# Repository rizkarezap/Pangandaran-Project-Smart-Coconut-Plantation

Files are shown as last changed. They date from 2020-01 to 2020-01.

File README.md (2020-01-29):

# Pangandaran Project: Smart Coconut Plantation
# Introduction

We see that some of our coconut farmers are having problems with their growing media. They cannot monitor the level of soil fertility in an exact manner so that they cannot provide proper care to the soil. From these problems we tried to make the device that we designed ergonomically. Farmers can use this tool easily and quick results with accuracy can be accounted for.

# The Device

We made this device using a microcontroller from the Arduino family, the Arduino Nano. We use analog pins to get data like
fertility,
pH
Light intensity,
soil moisture
simultaneously. The data is processed and displayed on a 64x64 LCD screen. Regarding the power source, we use a Lipo 3.7 V 800 mAh battery and add a charger module to recharge. We also added a Bluetooth communication module to send data from devices to smart devices, such as Android phones.

# The Tools

To make it easy to use, we recommend that you install the Arduino IDE. You can easily upload code using the device to the microcontroller that you are using.

# The Schematic

We make board designs that we have integrated with other devices. You can use Eagle CAD or KiCAD software to see the schematics we made.

# We Are Open To Discuss

We really hope to continue this product until we can distribute this device to a wider market. Therefore we expect your support. You can contact me through my email. All your support is very helpful for us.

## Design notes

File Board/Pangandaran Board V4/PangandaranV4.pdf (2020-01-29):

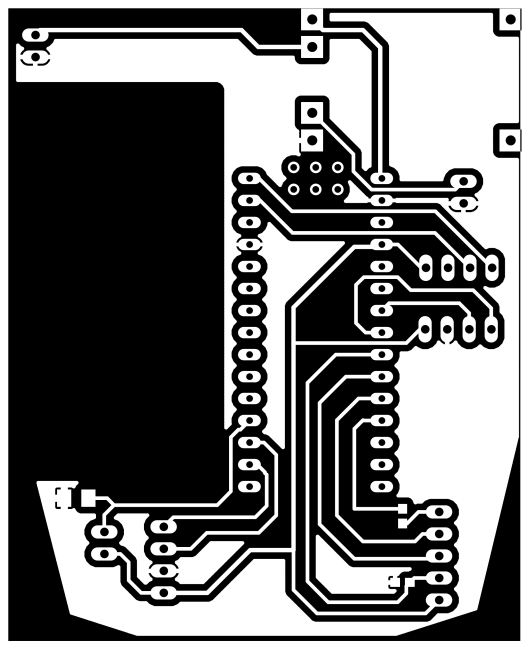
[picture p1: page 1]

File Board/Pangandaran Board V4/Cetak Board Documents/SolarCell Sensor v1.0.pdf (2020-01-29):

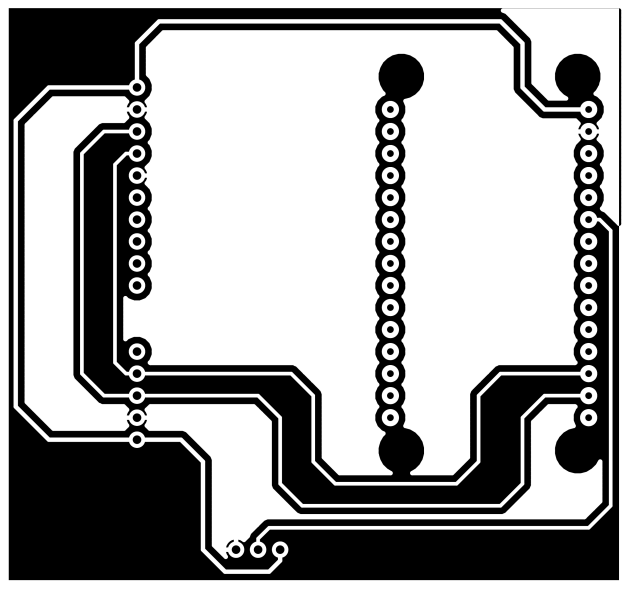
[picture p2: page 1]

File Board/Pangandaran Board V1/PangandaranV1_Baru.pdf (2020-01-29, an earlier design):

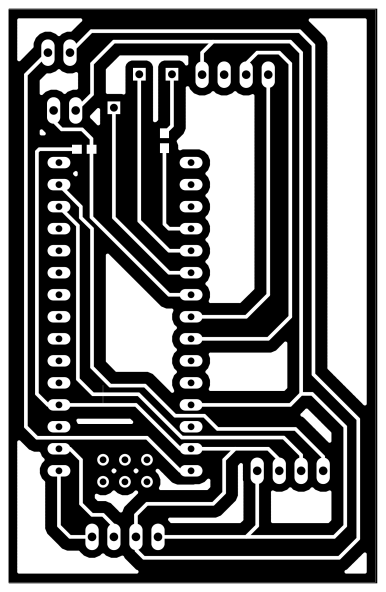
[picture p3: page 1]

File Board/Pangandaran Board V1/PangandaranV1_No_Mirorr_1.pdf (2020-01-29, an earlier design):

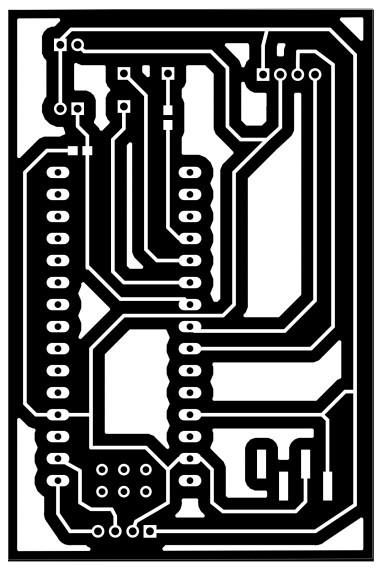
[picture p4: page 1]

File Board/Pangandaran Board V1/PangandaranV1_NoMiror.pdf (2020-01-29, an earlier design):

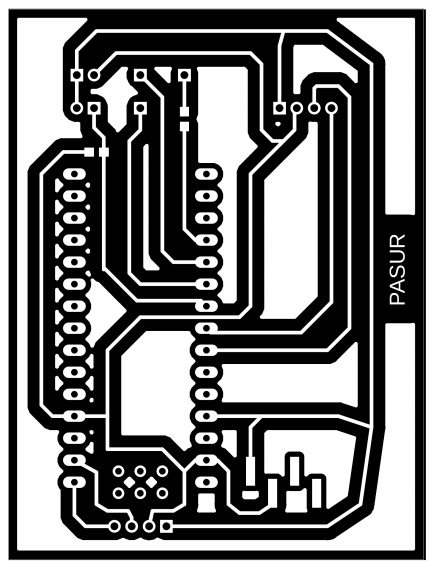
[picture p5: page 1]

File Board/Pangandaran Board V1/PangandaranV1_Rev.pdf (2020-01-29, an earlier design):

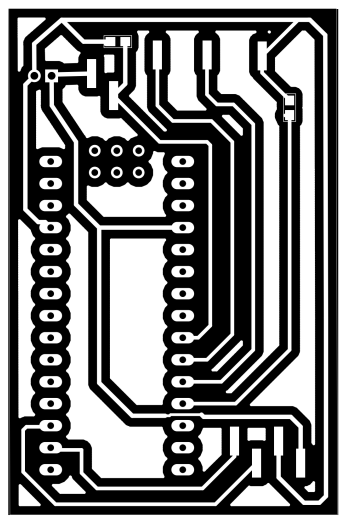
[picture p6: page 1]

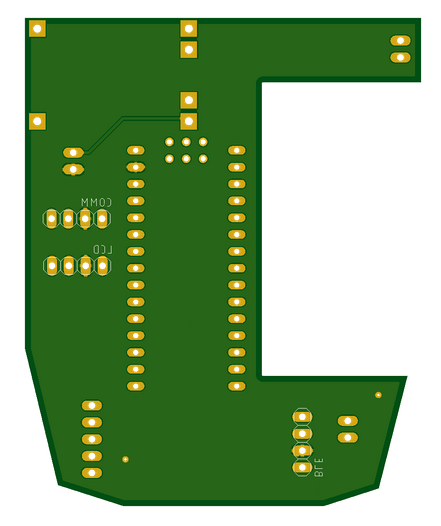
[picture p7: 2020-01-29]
Board/Bottom.png

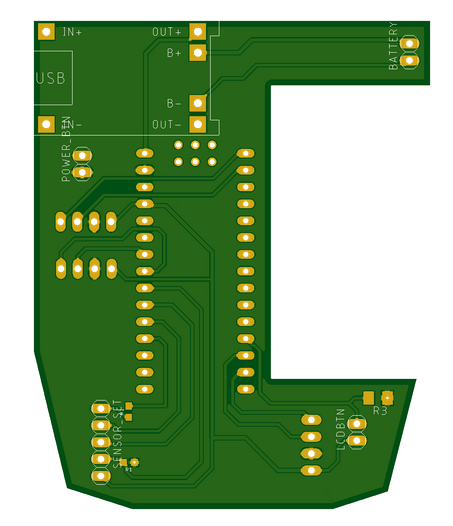
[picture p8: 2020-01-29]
Board/Top.png

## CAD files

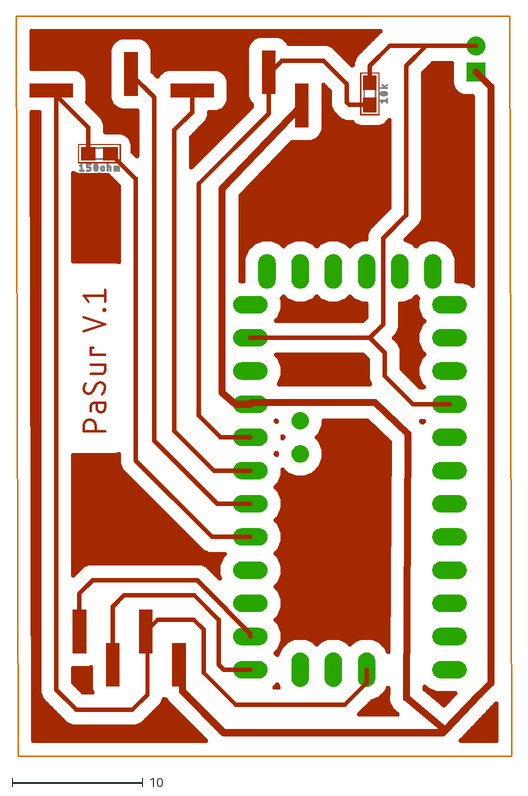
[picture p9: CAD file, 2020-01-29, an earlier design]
Board/Pangandaran Board V1/PangandaranV1.dxf
37.9 x 56.6

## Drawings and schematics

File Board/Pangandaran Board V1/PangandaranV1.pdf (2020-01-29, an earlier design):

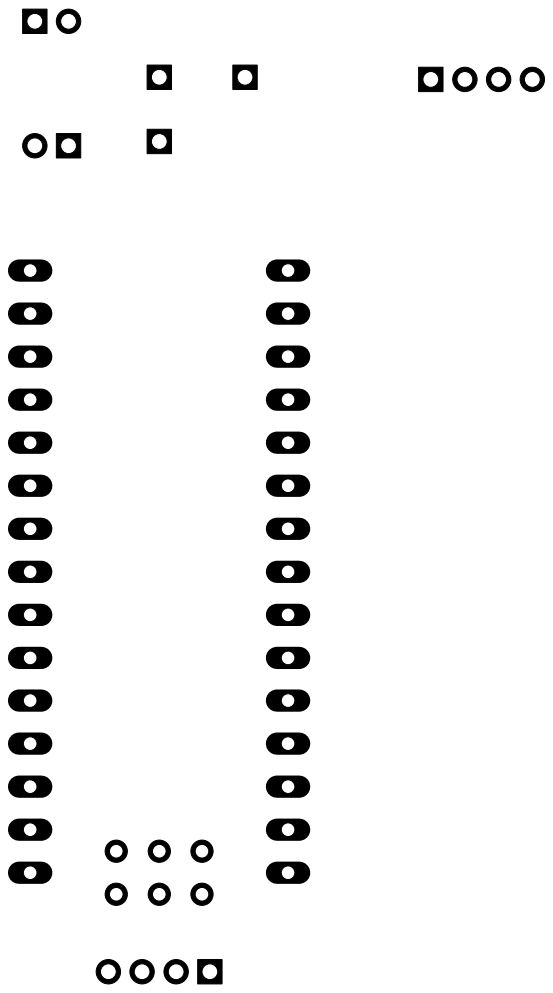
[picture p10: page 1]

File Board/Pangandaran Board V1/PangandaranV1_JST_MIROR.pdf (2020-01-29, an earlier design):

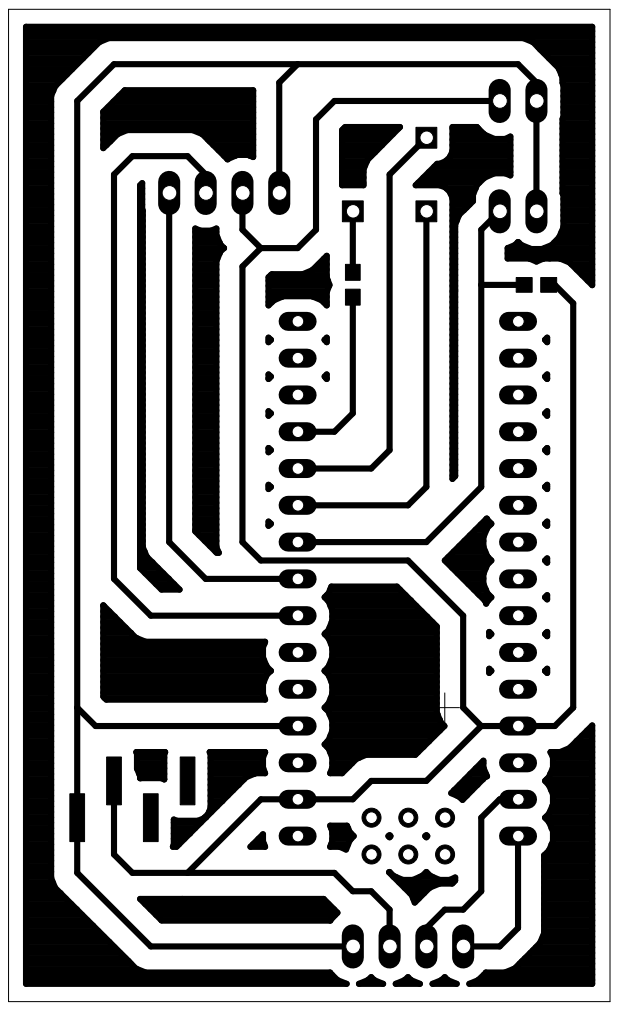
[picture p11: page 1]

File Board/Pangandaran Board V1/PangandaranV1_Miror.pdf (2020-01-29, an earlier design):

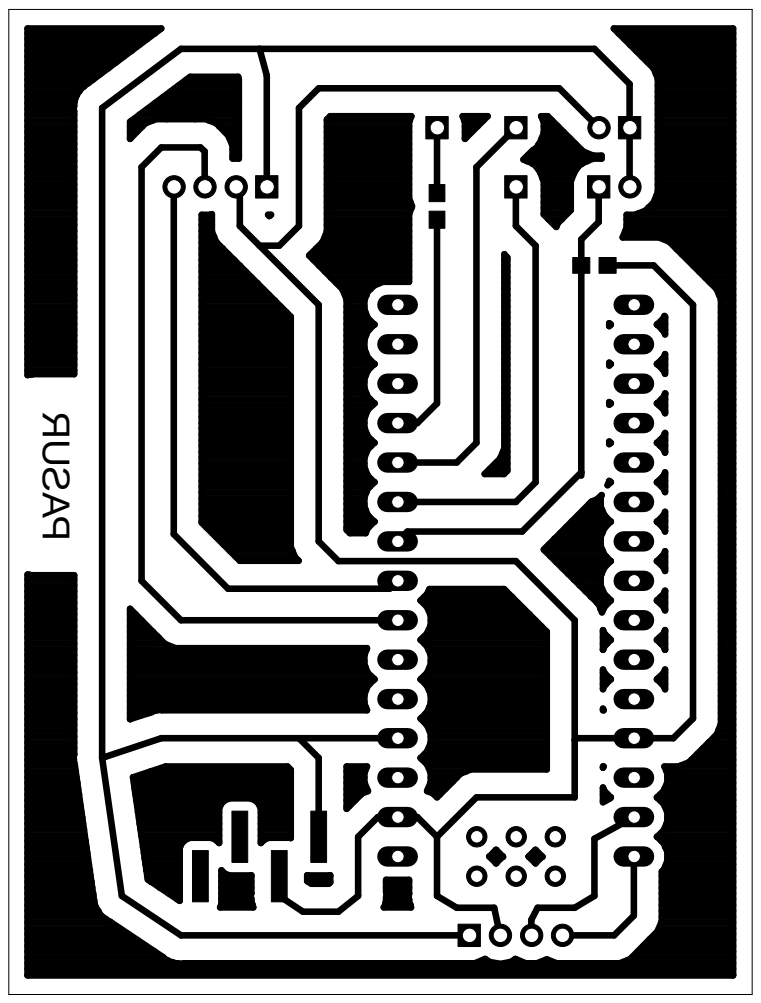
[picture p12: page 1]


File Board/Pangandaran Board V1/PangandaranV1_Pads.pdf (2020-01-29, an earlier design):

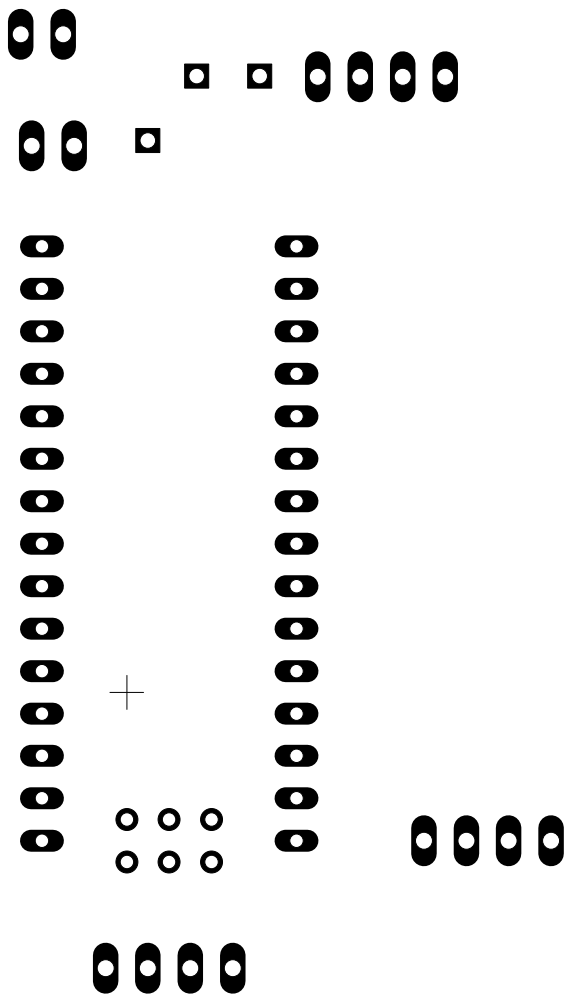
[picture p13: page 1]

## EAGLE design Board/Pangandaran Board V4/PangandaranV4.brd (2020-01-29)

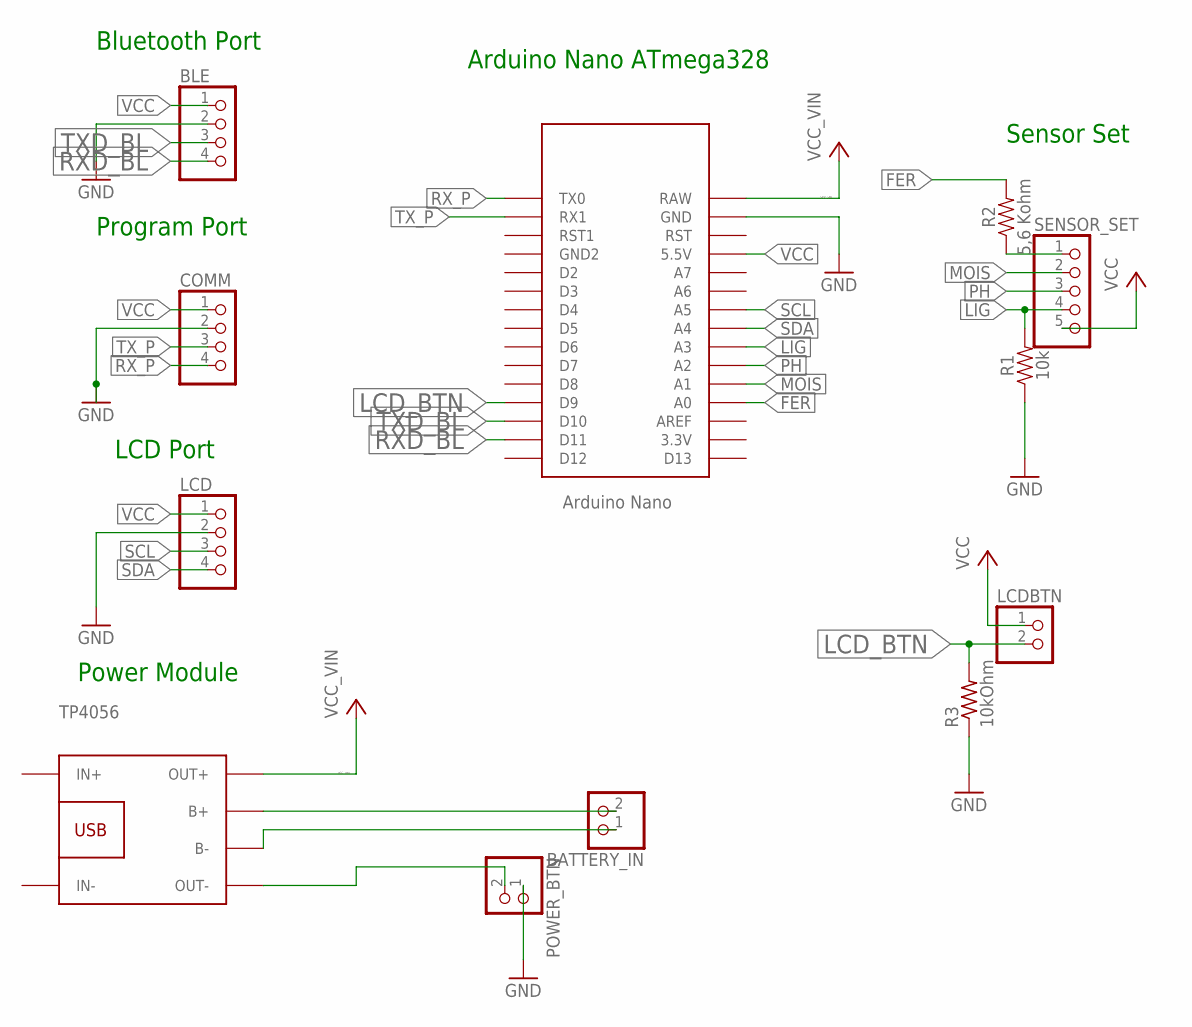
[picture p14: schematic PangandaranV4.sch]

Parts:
BATTERY_IN: PINHD-1X2; 1X02
BLE: PINHD-1X4; 1X04
COMM: PINHD-1X4; 1X04
LCD: PINHD-1X4; 1X04
LCDBTN: PINHD-1X2; 1X02
POWER_BTN: PINHD-1X2; 1X02
R1: 10k; 0603
R2: 5,6 Kohm; 0603
R3: 10kOhm; M1206
SENSOR_SET: PINHD-1X5; 1X05
TP4056: BATTERY-CHARGER-LI-PROT
U$2: NANO

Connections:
FER: R2.2, U$2.A0
GND: BLE.2, COMM.2, LCD.2, POWER_BTN.1, R1.1, R3.1, U$2.GND
LCD_BTN: LCDBTN.2, R3.2, U$2.D9
LIG: R1.2, SENSOR_SET.4, U$2.A3
MOIS: SENSOR_SET.2, U$2.A1
unnamed: R2.1, SENSOR_SET.1
unnamed: BATTERY_IN.2, TP4056.B+
unnamed: BATTERY_IN.1, TP4056.B-
unnamed: POWER_BTN.2, TP4056.OUT-
PH: SENSOR_SET.3, U$2.A2
RXD_BL: BLE.4, U$2.D11
RX_P: COMM.4, U$2.TX0
SCL: LCD.3, U$2.A5
SDA: LCD.4, U$2.A4
TXD_BL: BLE.3, U$2.D10
TX_P: COMM.3, U$2.RX1
VCC: BLE.1, COMM.1, LCD.1, LCDBTN.1, SENSOR_SET.5, U$2.5V (5.5V)
VCC_VIN: TP4056.OUT+, U$2.RAW

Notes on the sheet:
Power Module
Program Port
Arduino Nano ATmega328
LCD Port
Bluetooth Port
Sensor Set

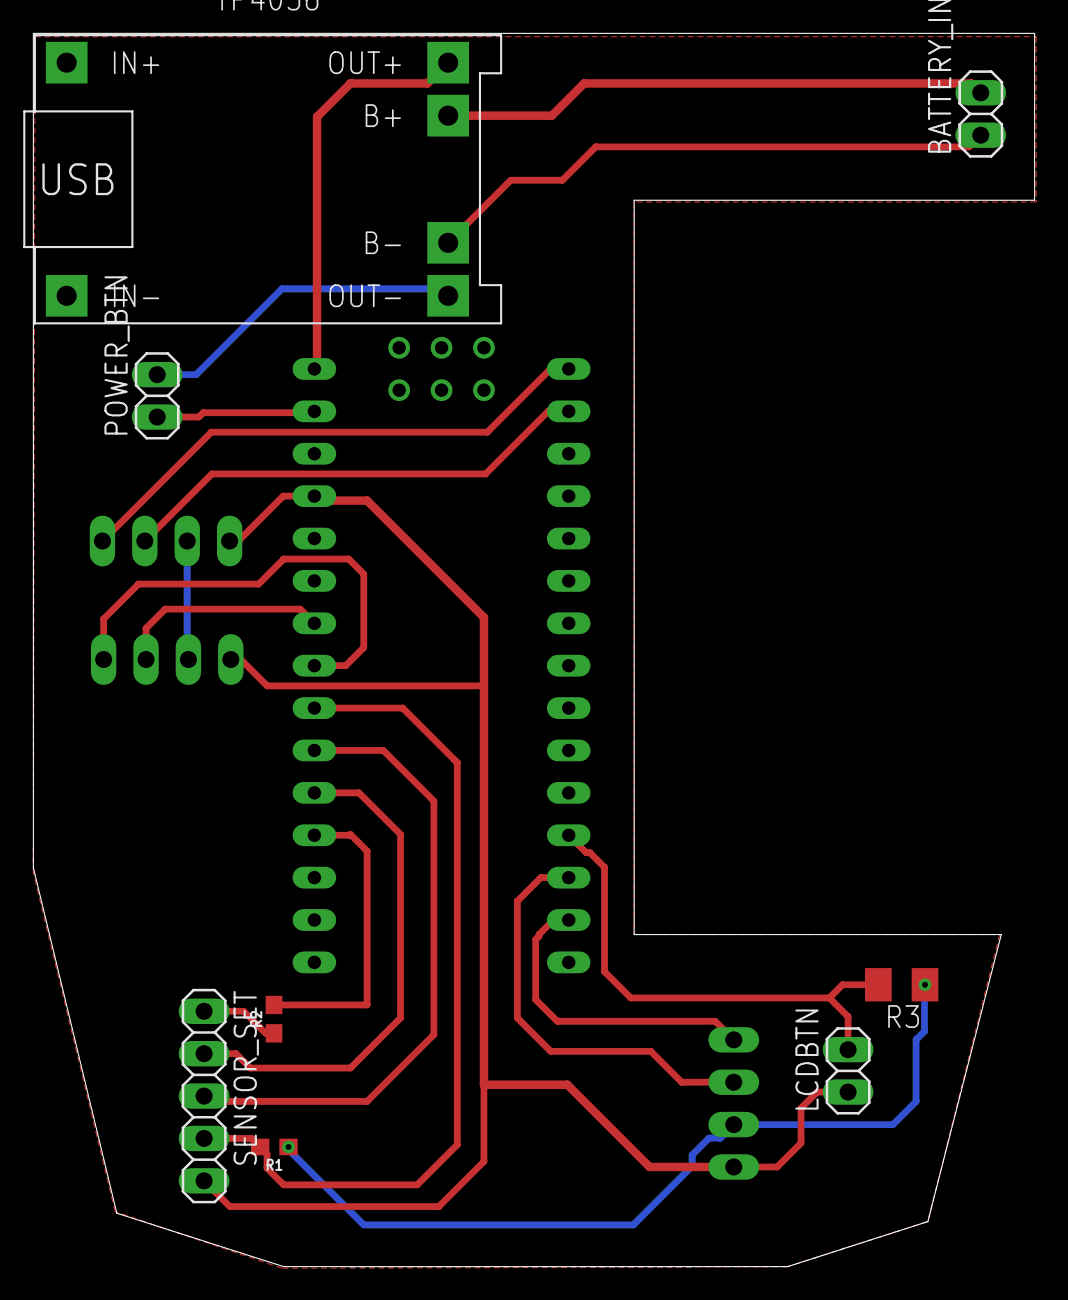
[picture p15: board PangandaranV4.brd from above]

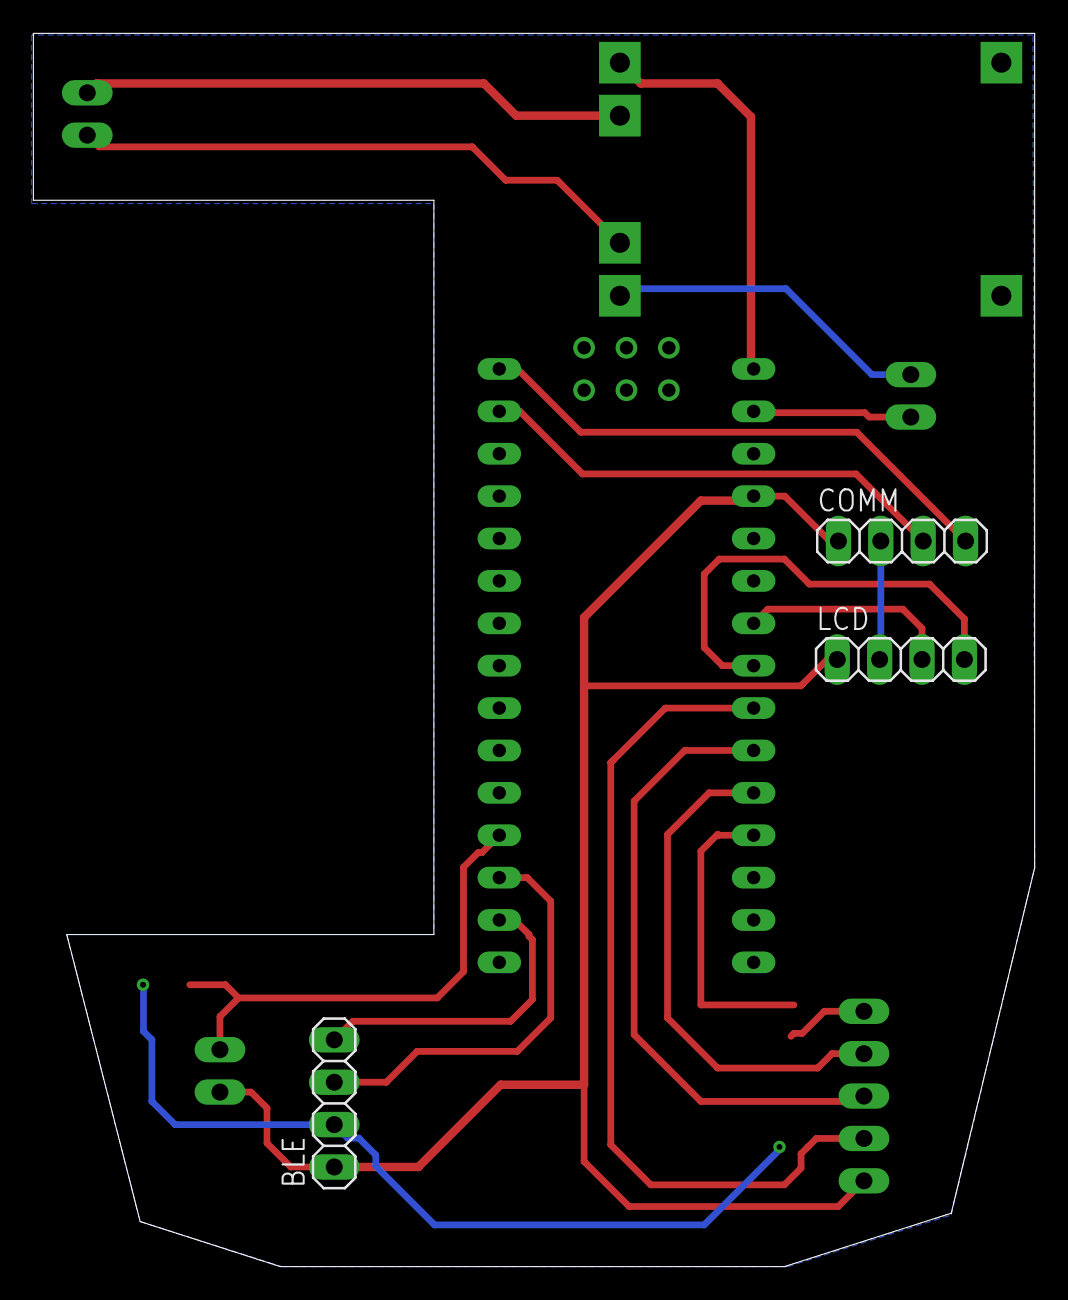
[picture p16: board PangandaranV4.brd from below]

Board: 2 copper layers, 60.0 x 73.9 mm, 12 parts (4 on the bottom side), 18 nets.

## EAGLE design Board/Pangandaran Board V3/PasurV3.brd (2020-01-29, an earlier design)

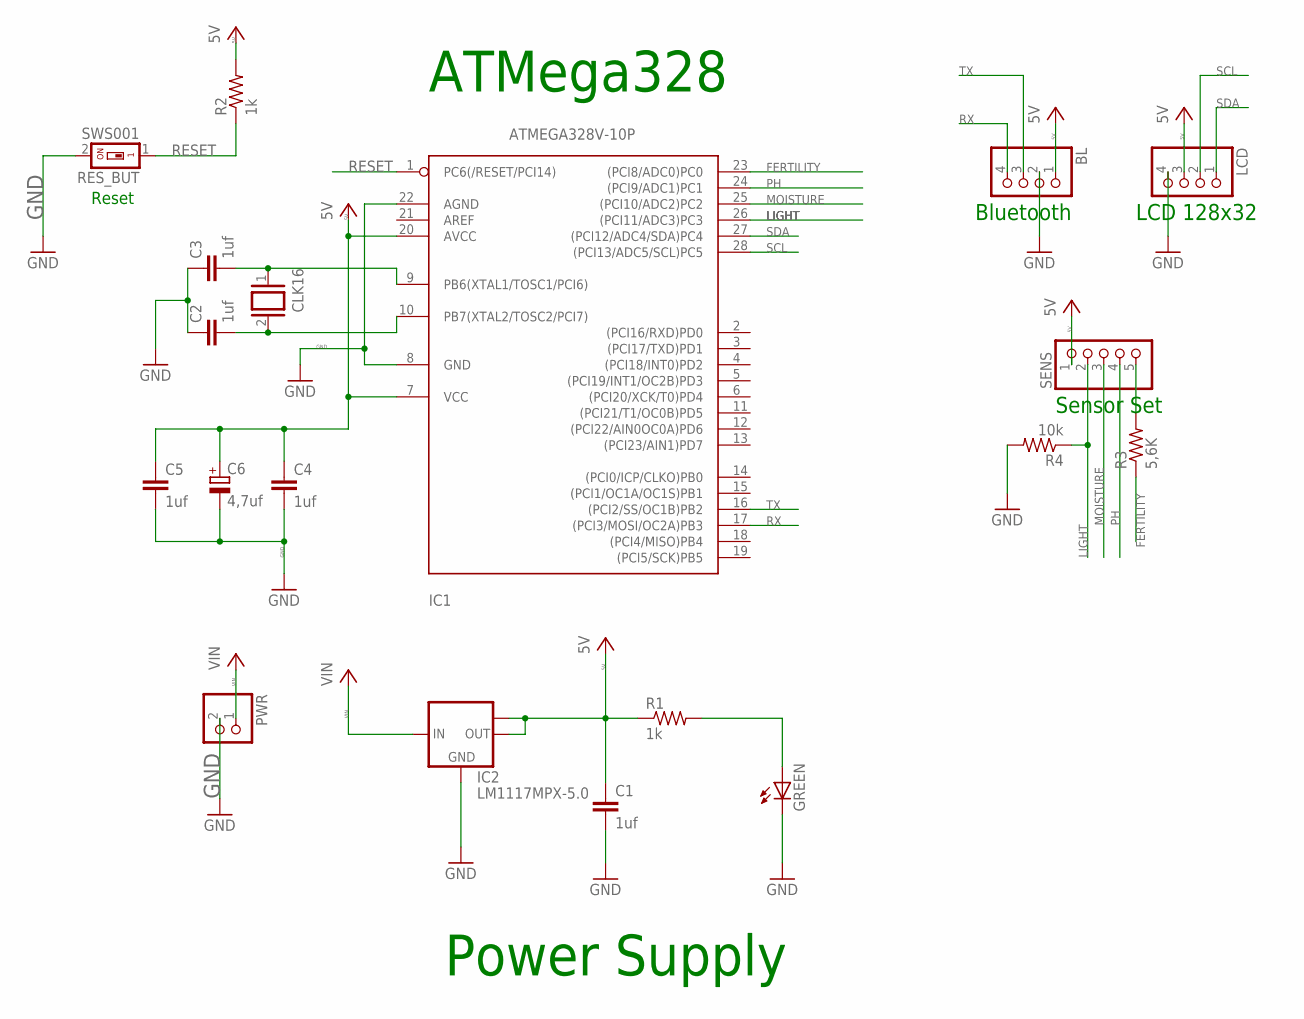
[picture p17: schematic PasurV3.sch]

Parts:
BL: PINHD-1X4; 1X04
C1, C2, C3, C4, C5: 1uf; C1206
C6: 4,7uf; A/3216-18W
CLK16: XTAL/S; QS
GREEN: LED_E; LED_1206
IC1: ATMEGA328V-10P; DIL28-3
IC2: LM1117MPX-5.0; SOT223
LCD: PINHD-1X4; 1X04
PWR: PINHD-1X2; 1X02
R1, R2: 1k; M1206
R3: 5,6K; M1206
R4: 10k; M1206
RES_BUT: SWS001; SMS-001
SENS: PINHD-1X5; 1X05

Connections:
5V: BL.1, C1.1, C4.1, C5.1, C6.+, IC1.7 (VCC), IC1.20 (AVCC), IC2.2 (OUT), IC2.TAB (OUT1), LCD.3, R1.1, R2.2, SENS.1
FERTILITY: IC1.23 ((PCI8/ADC0)PC0), R3.1
GND: BL.2, C1.2, C2.1, C3.1, C4.2, C5.2, C6.-, GREEN.C, IC1.8 (GND), IC1.22 (AGND), IC2.1 (GND), LCD.4, PWR.2, R4.2, RES_BUT.2
LIGHT: IC1.26 ((PCI11/ADC3)PC3), R4.1, SENS.2
MOISTURE: IC1.25 ((PCI10/ADC2)PC2), SENS.3
unnamed: C3.2, CLK16.1, IC1.9 (PB6(XTAL1/TOSC1/PCI6))
unnamed: C2.2, CLK16.2, IC1.10 (PB7(XTAL2/TOSC2/PCI7))
unnamed: GREEN.A, R1.2
unnamed: R3.2, SENS.5
PH: IC1.24 ((PCI9/ADC1)PC1), SENS.4
RESET: IC1.1 (PC6(/RESET/PCI14)), R2.1, RES_BUT.1
RX: BL.4, IC1.17 ((PCI3/MOSI/OC2A)PB3)
SCL: IC1.28 ((PCI13/ADC5/SCL)PC5), LCD.2
SDA: IC1.27 ((PCI12/ADC4/SDA)PC4), LCD.1
TX: BL.3, IC1.16 ((PCI2/SS/OC1B)PB2)
VIN: IC2.3 (IN), PWR.1

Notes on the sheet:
Power Supply
Reset
ATMega328
Bluetooth
LCD 128x32
Sensor Set

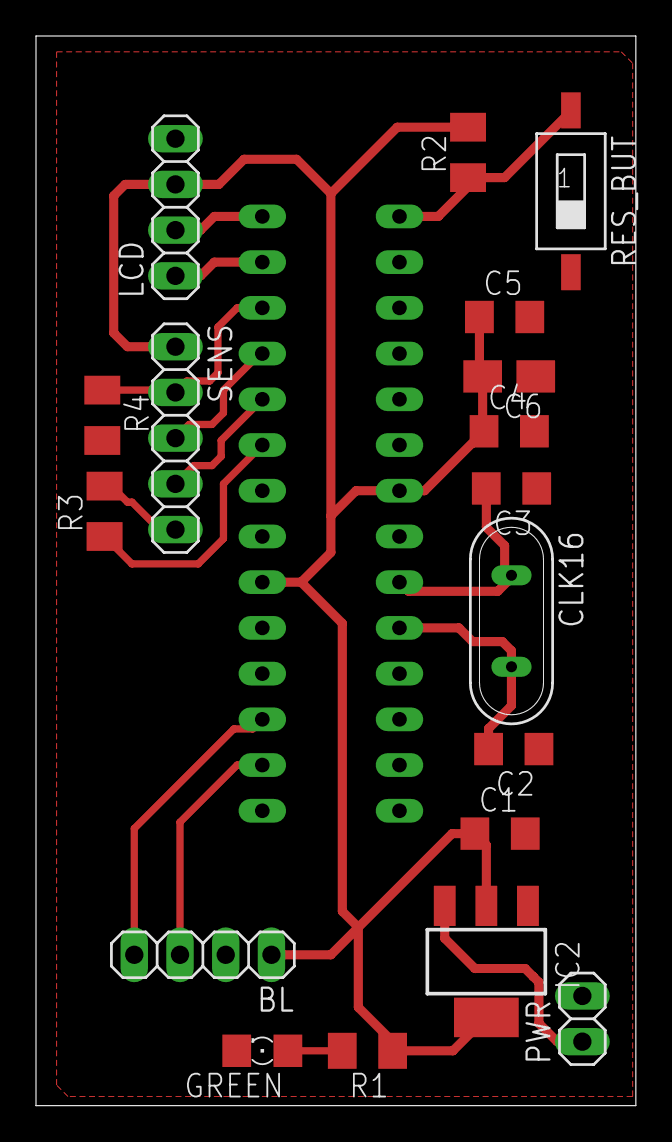
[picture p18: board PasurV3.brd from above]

Board: 2 copper layers, 33.3 x 59.4 mm, 19 parts (1 on the bottom side), 16 nets.

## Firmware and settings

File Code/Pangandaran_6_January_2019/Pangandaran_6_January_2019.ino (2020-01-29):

/*
   Dokumentasi pengerjaan code untuk proyek Pangandaran.

   Versi 1.01

   Pengerjaan board menggunakan arduino Nano

   Sensor yang digunakan adalah :
      1. pH
      2. Moistuer
      3. Fertility
      4. Cahaya

  Definisi Port untuk sensor
      1. pH ada di A2
      2. Moisture A1
      3. Fertility Perpauan A1 dan A0
      4. Cahaya A3


  Penambahan LCD pada tanggal 16 Juli 2018

   LCD yang digunakan adalah LCD 128*64 I2C 0X3C

  Penambahan Prosedur bahwa data yang dikirim adalah satu string dengan format pH, Moisture, Fertility, Cahaya dengan format "pH123#Mo123#Fe123#Li123"

    26 Juli 2018

  Perbahuran kode untuk pengambilan data pH. Pembaruan pengambilan data dilakukan karena pengambilan data pH tidak begitu akurat dan memiliki jangka nilai yang jauh.

   21 Desember

   Perbaruan kode yang ditujukan untuk dapat dengan mudah mengganti nilai kalibrasi pada perangkat. Sistem yang digunakan adalah dengan menyimpan data kalibrasi pada EEPEROM dengan deskripsi alamat sebagai berikut
      Address 0 : pH
      Address 1 : Moisture
      Address 2 & 3 : Fertility
      Address 4 : Light
*/


#include <SPI.h>
#include <Wire.h>
#include <SoftwareSerial.h>
#include <Adafruit_GFX.h>       // Lbrary Untuk Grapics LCD
#include <Adafruit_SSD1306.h>   // Library For LCD
#include <EEPROM.h>
/*
   Define Port Untuk sensor
*/
#define pH A2
#define Moisture A1
#define Fertility A0
#define Cahaya A3
#define LCD 9

int DatapH,DataMoisture,DataFertility,DataCahaya;
int PurepH,PureMos,PureFer,PureLi;
float KalpH = 99.198 ,KalMos = 102.337 ,KalFer = 321.13 ,KalLi = 102.3; // Default nilai pada kalibrasi
String readFromBLE = "",readKal = "";
int looppH = 0,signpH,loopFer = 0,signFer,loopMos = 0,signMos,loopLi = 0,signLi;

/*
   Define untuk LCD
*/
#define OLED_RESET 4
Adafruit_SSD1306 display(OLED_RESET);
#define NUMFLAKES 10
#define XPOS 0
#define YPOS 1
#define DELTAY 2
#define LOGO16_GLCD_HEIGHT 16
#define LOGO16_GLCD_WIDTH  16

static const unsigned char PROGMEM Logo_Light[] = // Logo Australia Global Alumni
{ B10000000, B00000001,
  B10000001, B10000001,
  B11000001, B10000011,
  B01100001, B10000110,
  B00000000, B00000000,
  B00000011, B11100000,
  B00000111, B11110000,
  B11011111, B11111011,
  B11011111, B11111011,
  B00001111, B11110000,
  B00000111, B11100000,
  B00000000, B00000000,
  B01100001, B10000110,
  B11000001, B10000011,
  B10000001, B10000001,
  B10000001, B10000001
};
static const unsigned char PROGMEM Logo_Moisture[] = // Logo Australia Global Alumni
{ B00000100, B00000000,
  B00000011, B00000000,
  B00000011, B1000000,
  B00000001, B11100000,
  B00000001, B11110000,
  B00000001, B11111000,
  B00000111, B11111100,
  B00011111, B11111110,
  B00111111, B11111111,
  B01111111, B11111111,
  B01111111, B11111111,
  B01111111, B11111111,
  B00111111, B11111110,
  B00011111, B11111110,
  B00001111, B11111000,
  B00000001, B11000000
};

static const unsigned char PROGMEM Logo_pH[] = // Logo Australia Global Alumni
{ B00000000, B00000000,
  B00000011, B00001100,
  B00000011, B00001100,
  B00000011, B00001100,
  B00000011, B11111100,
  B00000011, B00001100,
  B00000011, B00001100,
  B00000011, B11001100,
  B00111111, B11001100,
  B01100011, B1100000,
  B01100011, B11000000,
  B01100000, B11000000,
  B01111111, B11000000,
  B01100000, B00000000,
  B01100000, B00000000,
  B01100000, B00000000
};

static const unsigned char PROGMEM Logo_Fertility[] = // Logo Australia Global Alumni
{ B00000000, B00011111,
  B00000000, B00111111,
  B11000000, B01111111,
  B11111100, B01111110,
  B01111110, B00011100,
  B01111110, B01110000,
  B01111111, B11100000,
  B00000011, B00000000,
  B00001111, B00000000,
  B00011100, B00000000,
  B01111000, B00000000,
  B01110000, B00000000,
  B01110000, B00000000,
  B11110000, B00000000,
  B11100000, B00000000,
  B11100000, B00000000
};


SoftwareSerial BlueT(10, 11); // RX | TX

void setup()   {
  BlueT.begin(9600);
  display.begin(SSD1306_SWITCHCAPVCC, 0x3C);  // initialize with the I2C addr 0x3C (for the 128x64)
  display.clearDisplay();
  pinMode(LCD, INPUT);
  delay(1000);
  testscrolltext();
  ReadEEPROM();
  //Serial.begin(9600);
}

void loop() {

  if (digitalRead(LCD))
  {
    /*
       Get Data Moisture
    */
    DataMoisture = analogRead(Moisture);
    while (loopMos < 10 ) {
      if (loopMos == 0) {
        signMos = DataMoisture;
        loopMos++;
      }
      else if (abs(DataMoisture - signMos) < 150) {
        loopMos ++;
      }
      else {
        loopMos = 0;
      }
      delay(50);
      DataMoisture = analogRead(Moisture);
    }
    loopMos = 0;
    PureMos = DataMoisture / KalMos ;
    display.clearDisplay();
    /*
        Get Data Fertility
    */
    DataFertility = analogRead(Fertility);
    while (loopFer < 10 ) {
      if (loopFer == 0) {
        signFer = DataFertility;
        loopFer++;
      }
      else if (abs(DataFertility - signFer) < 340) {
        loopFer ++;
      }
      else {
        loopFer = 0;
      }
      delay(50);
      DataFertility = analogRead(Fertility);
    }
    loopFer = 0;
    DataFertility = DataFertility + DataMoisture;
    PureFer = (DataFertility / KalFer);
    /*
       Get Data Light
    */
    int DataCahaya = analogRead(Cahaya);
    PureLi = DataCahaya / KalLi;
    /*
       Get Data pH
    */
    DatapH = analogRead(pH);
    while (looppH < 10 ) {
      if (looppH == 0) {
        signpH = DatapH;
        looppH++;
      }
      else if (abs(DatapH - signpH) < 120) {
        looppH ++;
      }
      else {
        looppH = 0;
      }
      delay(50);
      DatapH = analogRead(pH);
    }
    looppH = 0;
    if (DatapH < 650) {
      PurepH = (1023 - DatapH) / KalpH;
    }
    else {
      PurepH = DatapH / KalpH;
    }
    /*
       Show to LCD
    */
    display.clearDisplay();
    display.drawBitmap(64, 0,  Logo_Moisture, 16, 16, 1);
    display.drawBitmap(0, 16,  Logo_Fertility, 16, 16, 1);
    display.drawBitmap(0, 0,  Logo_pH, 16, 16, 1);
    display.drawBitmap(64, 16,  Logo_Light, 16, 16, 1);
    display.display();
    display.setTextSize(2);
    display.setTextColor(WHITE);
    display.setCursor(20, 0);
    if(PurepH > 9 ) display.println("~");
    else display.println(PurepH);
    display.setCursor(20, 16);
    if(PureFer > 8 ) display.println("~");
    else display.println(PureFer);
    display.setCursor(84, 0);
    if(PureMos > 10 ) display.println("~");
    else display.println(PureMos);
    display.setCursor(84, 16);
    if(PureLi > 10 ) display.println("~");
    else display.println(PureLi);
    display.display();
    delay(10);

  }
  else {
    display.clearDisplay();
    display.display();
    if (BlueT.available()) {
      display.clearDisplay();
      while (char(BlueT.read()) != '\r' or char(BlueT.read()) != '\n') {
        readFromBLE = readFromBLE + (char(BlueT.read()));
        delay(4);
      }
      if (readFromBLE == "6171") {
        delay(4500);
        DatapH = analogRead(pH);
        while (looppH < 10 ) {
          if (looppH == 0) {
            signpH = DatapH;
            looppH++;
          }
          else if (abs(DatapH - signpH) < 120) {
            looppH ++;
          }
          else {
            looppH = 0;
          }
          delay(50);
          DatapH = analogRead(pH);
        }
        looppH = 0;
        delay(10);
        BlueT.println("pH");
        delay(50);
        BlueT.println(DatapH);
        delay(50);
        BlueT.println("#");
      }
      if (readFromBLE == "9024") {
        delay(4500);
        DataMoisture = analogRead(Moisture);
        while (loopMos < 10 ) {
          if (loopMos == 0) {
            signMos = DataMoisture;
            loopMos++;
          }
          else if (abs(DataMoisture - signMos) < 150) {
            loopMos ++;
          }
          else {
            loopMos = 0;
          }
          delay(50);
          DataMoisture = analogRead(Moisture);
        }
        loopMos = 0;
        delay(10);
        BlueT.println("Mo");
        delay(50);
        BlueT.println(DataMoisture);
        delay(50);
        BlueT.println("#");
      }
      if (readFromBLE == "3024") {
        delay(4500);
        DataFertility = analogRead(Fertility);
        while (loopFer < 10 ) {
          if (loopFer == 0) {
            signFer = DataFertility;
            loopFer++;
          }
          else if (abs(DataFertility - signFer) < 340) {
            loopFer ++;
          }
          else {
            loopFer = 0;
          }
          delay(50);
          DataFertility = analogRead(Fertility);
        }
        loopFer = 0;
        DataMoisture = analogRead(Moisture);
        while (loopMos < 10 ) {
          if (loopMos == 0) {
            signMos = DataMoisture;
            loopMos ++;
          }
          else if (abs(DataMoisture - signMos) < 150) {
            loopMos ++;
          }
          else {
            loopMos = 0;
          }
          delay(50);
          DataMoisture = analogRead(Moisture);
        }
        loopMos = 0;
        DataFertility = DataFertility + DataMoisture;
        delay(10);
        BlueT.println("Fe");
        delay(50);
        BlueT.println(DataFertility);
        delay(50);
        BlueT.println("#");
      }
      if (readFromBLE == "8024") {
        delay(4500);
        DataCahaya = analogRead(Cahaya);
        delay(10);
        BlueT.println("Li");
        delay(50);
        BlueT.println(DataCahaya);
        delay(50);
        BlueT.println("#");
      }
      if (readFromBLE == "8029") {
        delay(4500);
        sendDataKal_BLE();
      }
      if (readFromBLE == "8659") {
        displaynotickalibrasi();
        configure_kalibration();
      }
    }
    readFromBLE = "";
  }
}

void sendDataKal_BLE() {
  BlueT.println("pH");
  delay(50);
  BlueT.println(KalpH);
  delay(50);
  BlueT.println("#");
  delay(50);
  BlueT.println("Mo");
  delay(50);
  BlueT.println(KalMos);
  delay(50);
  BlueT.println("#");
  delay(50);
  BlueT.println("Fe");
  delay(50);
  BlueT.println(KalFer);
  delay(50);
  BlueT.println("#");
  delay(50);
  BlueT.println("Li");
  delay(50);
  BlueT.println(KalLi);
  delay(50);
  BlueT.println("#");
}

void displaynotickalibrasi() {
  display.setTextSize(1.8);
  display.setTextColor(WHITE);
  display.setCursor(30, 0);
  display.println("Calibration");
  display.display();
}

void testscrolltext(void) {
  display.setTextSize(1.8);
  display.setTextColor(WHITE);
  display.setCursor(30, 0);
  display.println("Smart");
  display.setTextSize(2);
  display.setTextColor(WHITE);
  display.setCursor(10, 8);
  display.println("Coconut");
  display.setTextSize(1);
  display.setTextColor(WHITE);
  display.setCursor(20, 24);
  display.println("Plantation");
  display.setTextSize(2);
  display.setTextColor(WHITE);
  display.setCursor(10, 0);
  display.display();
  delay(500);

  display.startscrollright(0x00, 0xFF);
  delay(1000);
  display.stopscroll();
  delay(1000);
  display.startscrollleft(0x00, 0xFF);
  delay(1000);
  display.stopscroll();
}

//void GetAllDataSensor() {
//  DataMoisture = analogRead(Moisture);
//  while (loopMos < 10 ) {
//    if (loopMos == 0) {
//      signMos = DataMoisture;
//    }
//    else if (abs(DataMoisture - signMos) < 150) {
//      loopMos ++;
//    }
//    else {
//      loopMos = 0;
//    }
//    delay(150);
//    DataMoisture = analogRead(Moisture);
//  }
//  loopMos = 0;
//
//  DataFertility = analogRead(Fertility);
//  while (loopFer < 10 ) {
//    if (loopFer == 0) {
//      signFer = DataFertility;
//    }
//    else if (abs(DataFertility - signFer) < 340) {
//      loopFer ++;
//    }
//    else {
//      loopFer = 0;
//    }
//    delay(150);
//    DataFertility = analogRead(Fertility);
//  }
//  loopFer = 0;
//
//  DatapH = analogRead(pH);
//  while (looppH < 10 ) {
//    if (looppH == 0) {
//      signpH = DatapH;
//    }
//    else if (abs(DatapH - signpH) < 120) {
//      looppH ++;
//    }
//    else {
//      looppH = 0;
//    }
//    delay(150);
//    DatapH = analogRead(pH);
//  }
//  looppH = 0;
//
//  DataCahaya = analogRead(Cahaya);
//  sendData_BLE(DatapH, DataMoisture, DataFertility, DataCahaya);
//}

// EEPROM Configuration
void WriteEEPROM_Fer(int address, int val){
  if (val > 255 && address == 2 ){
    EEPROM.write(2,255);
    EEPROM.write(3,val - 255);
  }
  else if (address = 2 && val <= 255){
    EEPROM.write(2,val);
    EEPROM.write(3,0);
  }
}

void WriteEEPROM(int address,int val){
  EEPROM.write(address,val);
}

// End Configuration EEPROM

void ReadEEPROM() {
  KalpH = EEPROM.read(0);
  KalMos = EEPROM.read(1);
  KalFer = EEPROM.read(2) + EEPROM.read(3);
  KalLi = EEPROM.read(4);
}


/*
   Konfigurasi Kalibrasi Belum selesai
*/
void configure_kalibration() {
  readKal = "";
  String Val = "";
  int NotifValWrite = 0;
  int Value;
  float Average_data = 0;
  bool done = false;
  while (not done) {
    if (BlueT.available()) {
      readKal = "";
      Value = 0;
      NotifValWrite = 0;
      display.clearDisplay();
      while (char(BlueT.read()) != '\r' or char(BlueT.read()) != '\n') {
        readKal = readKal + (char(BlueT.read()));
        delay(2);
      }
      if (readKal[0] == 'M') { // Done at 26 Desember
        int length_s = readKal.length();
        for (int i = 1; i <= length_s ; i++) {
          Val = Val + readKal[i];
        }
        Value = Val.toInt();
        delay(4500);
        Average_data = 0;
        DataMoisture = analogRead(Moisture);
        while (loopMos < 10 ) {
          if (loopMos == 0) {
            signMos = DataMoisture;
            loopMos++;
            Average_data += DataMoisture;
          }
          else if (abs(DataMoisture - signMos) < 150) {
            loopMos ++;
            Average_data += DataMoisture;
          }
          else {
            loopMos = 0;
            Average_data = 0;
          }
          delay(50);
          DataMoisture = analogRead(Moisture);
        }
        loopMos = 0;
        NotifValWrite = (Average_data / 10) / Value;
        WriteEEPROM(1, ((Average_data / 10) / Value));
        done = true;
      }
      if (readKal[0] == 'L') { // Done at 26 Desember
        int length_s = readKal.length();
        for (int i = 1; i <= length_s ; i++) {
          Val = Val + readKal[i];
        }
        Value = Val.toInt();
        delay(4500);
        Average_data = 0;
        DataCahaya = analogRead(Cahaya);
        NotifValWrite = (DataCahaya / Value);
        WriteEEPROM(4, (DataCahaya / Value));
        done = true;
      }
      if (readKal[0] == 'P') { // Done 26 Desember
        int length_s = readKal.length();
        for (int i = 1; i <= length_s ; i++) {
          Val = Val + readKal[i];
        }
        Value = Val.toInt();
        Average_data = 0;
        delay(4500);
        DatapH = analogRead(pH);
        while (looppH < 10 ) {
          if (looppH == 0) {
            signpH = DatapH;
            looppH++;
            Average_data += DatapH;
          }
          else if (abs(DatapH - signpH) < 120) {
            looppH ++;
            Average_data += DatapH;
          }
          else {
            looppH = 0;
            Average_data = 0;
          }
          delay(50);
          DatapH = analogRead(pH);
        }
        looppH = 0;
        NotifValWrite = (Average_data / 10) / Value;
        WriteEEPROM(0, ((Average_data / 10) / Value));
        done = true;
      }
      if (readKal[0] == 'F') { // Done at 26 Desember
        int length_s = readKal.length();
        for (int i = 1; i <= length_s ; i++) {
          Val = Val + readKal[i];
        }
        Value = Val.toInt();
        Average_data = 0;
        while (loopFer < 10 ) {
          if (loopFer == 0) {
            signFer = DataFertility;
            loopFer++;
          }
          else if (abs(DataFertility - signFer) < 340) {
            loopFer ++;
          }
          else {
            loopFer = 0;
          }
          delay(50);
          DataFertility = analogRead(Fertility);
        }
        loopFer = 0;
        DataMoisture = analogRead(Moisture);
        while (loopMos < 10 ) {
          if (loopMos == 0) {
            signMos = DataMoisture;
            loopMos ++;
          }
          else if (abs(DataMoisture - signMos) < 150) {
            loopMos ++;
          }
          else {
            loopMos = 0;
          }
          delay(50);
          DataMoisture = analogRead(Moisture);
        }
        loopMos = 0;
        Average_data = DataFertility + DataMoisture;
        NotifValWrite = Average_data / Value;
        WriteEEPROM_Fer(2, (Average_data / Value));
        done = true;
      }
      if (readKal[0] == 'Q') {
        done = true;
      }
      if (done) {
        BlueT.println("Success Write#");
        delay(50);
        BlueT.println(NotifValWrite);
        delay(50);
        BlueT.println("Done Calibration");
        delay(50);
        BlueT.println("#");
      }

    }
  }
}

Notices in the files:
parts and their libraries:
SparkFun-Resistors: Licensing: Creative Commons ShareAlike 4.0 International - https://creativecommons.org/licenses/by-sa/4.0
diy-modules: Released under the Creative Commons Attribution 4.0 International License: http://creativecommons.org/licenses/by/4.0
